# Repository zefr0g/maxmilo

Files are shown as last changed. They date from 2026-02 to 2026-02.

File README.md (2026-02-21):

# maxmilo - Contrôleur ESPHome pour Climatiseurs Mitsubishi

Ce projet vous permet de contrôler votre unité CVC Mitsubishi (avec un port CN105) en utilisant un ESP8266 (ESP-01) et ESPHome. Il remplace l'interface WiFi Mitsubishi originale **MAC-587IF-E** pour une fraction du prix, tout en offrant plus de fonctionnalités. Il est basé sur l'excellent travail de [echavet/MitsubishiCN105ESPHome](https://github.com/echavet/MitsubishiCN105ESPHome).

Il offre une interface moderne via Home Assistant ou un navigateur web, et dispose d'un portail captif pour une configuration WiFi facile.

[🇬🇧 Read the English version here](README_EN.md)

<p align="center">
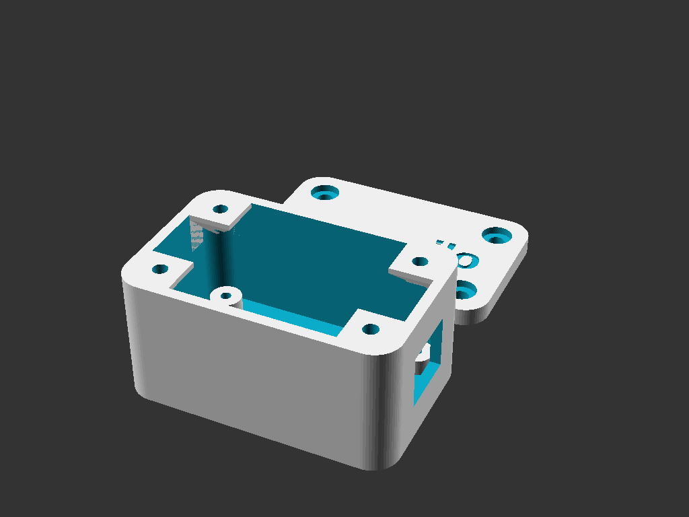
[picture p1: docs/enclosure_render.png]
Rendu 3D du boîtier
  
</p>

<p align="center">
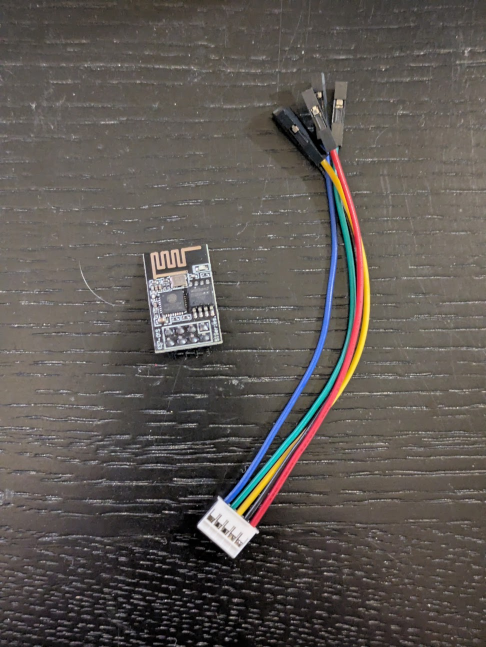
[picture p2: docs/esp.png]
ESP-01 et câble CN105
  
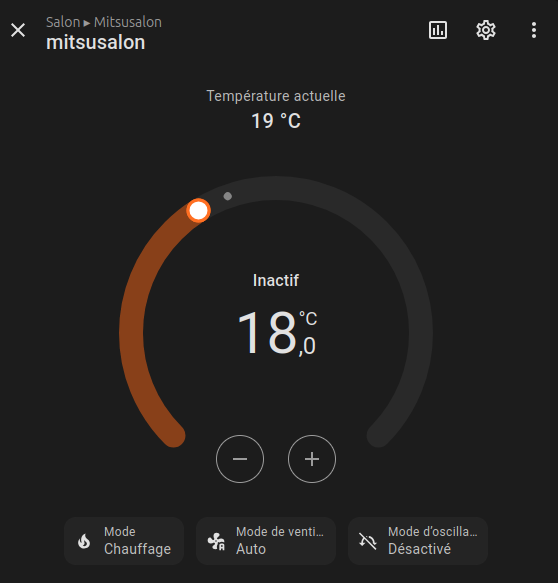
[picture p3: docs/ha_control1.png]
Interface Home Assistant 1
  
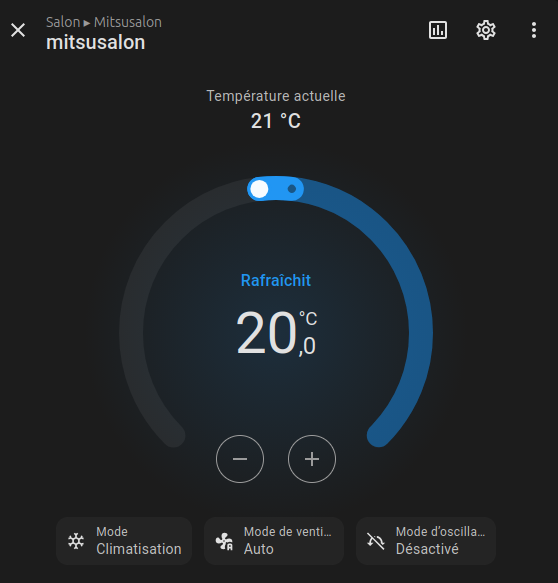
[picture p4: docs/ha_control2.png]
Interface Home Assistant 2
  
</p>

## 🚀 Fonctionnalités

- **Installation en un clic :** Via l'installateur web, sans ligne de commande.
- **Portail Captif WiFi :** Connectez-vous au point d'accès du module pour configurer votre réseau local.
- **Renommage dynamique :** Changez le nom de votre unité directement depuis l'interface web.
- **Diagnostics Avancés :** Suivi de la force du signal WiFi (RSSI) et de l'uptime.
- **Intégration Home Assistant :** Découverte automatique via l'API Native.

## 📖 Documentation
- **[Guide d'Installation Étape par Étape](docs/installation.md)**
- **[Plan de la future carte PCB](docs/pcb_plan.md)**
- **Matériel Open Source :** Boîtier imprimable en 3D avec fixations sécurisées.

## 🛠 Matériel Requis

Pour fabriquer ce contrôleur, vous aurez besoin de :

1.  **Module ESP8266 ESP-01**
2.  **Adaptateur Série WiFi ESP-01** (Assure la régulation 5V vers 3.3V et l'adaptation de niveau logique)
3.  **Connecteur JST PAP-05V-S** (Connecteur 5 broches pour le port CN105)
4.  **Boîtier maxmilo** (Fichier SCAD fourni dans `hardware/`)

### Schéma de câblage (CN105 vers ESP-01)

| Broche CN105 | Fonction | Adaptateur ESP-01 |
| :--- | :--- | :--- |
| 1 | 12V | Non Connecté |
| 2 | GND | GND |
| 3 | 5V | VCC (5V) |
| 4 | TX | RX (GPIO3) |
| 5 | RX | TX (GPIO1) |

> ⚠️ **Attention :** Assurez-vous que votre adaptateur gère bien la conversion de niveau 5V vers 3.3V pour protéger l'ESP-01.

## 💻 Installation

### Option A : Installateur Web (Recommandé)
Flashez votre ESP-01 directement depuis votre navigateur (Chrome/Edge) sans rien installer !
👉 **[Cliquez ici pour utiliser l'Installateur Web maxmilo](https://zefr0g.github.io/maxmilo/web_installer/)**

### Option B : Installation Manuelle (CLI)
Si vous préférez compiler vous-même :

#### 1. Installer ESPHome
```bash
pip install esphome
```

#### 2. Flasher le Firmware
```bash
esphome run example.yaml
```

## 💰 Acheter un Kit
Vous ne voulez pas sourcer les pièces vous-même ? [Ouvrez une Issue sur GitHub](https://github.com/zefr0g/maxmilo/issues) pour commander un kit prêt à l'emploi.

## 🤝 Contribution
Les contributions sont les bienvenues ! N'hésitez pas à ouvrir une issue ou une pull request.

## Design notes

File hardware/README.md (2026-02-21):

# Matériel maxmilo - Liste des Pièces & Assemblage

Ce dossier contient les informations sur les composants physiques et le processus d'assemblage.

[🇬🇧 English version available here](README_EN.md)

## 📦 Liste des Pièces (BOM)

| Qté | Article | Description | Prix Approx. |
| :--- | :--- | :--- | :--- |
| 1 | ESP8266 ESP-01 | Microcontrôleur (Wi-Fi) | ~$2.00 |
| 1 | Adaptateur Série ESP-01 | Régulateur 5V et adaptateur de niveau | ~$1.50 |
| 1 | JST PAP-05V-S | Connecteur 5 broches (pour CN105) | ~$0.50 |
| 1 | Boîtier imprimé 3D | Boîtier pour les modules | (Minimal) |
| 4 | Inserts filetés M3 | Inserts à chaud pour fixer le couvercle | ~$1.00 |

## 💰 Acheter le Kit

- **Kit DIY :** Tous les composants inclus. Vous assemblez et flashez.
- **Assemblé & Pré-flashé :** Prêt à l'emploi.

### Comment commander
Pour acheter, merci d'**[ouvrir une issue sur GitHub](https://github.com/zefr0g/maxmilo/issues)**.

## 🛠 Instructions d'Assemblage

1.  **Préparer le connecteur :** Sertissez le connecteur PAP-05V-S avec 4 fils (GND, 5V, TX, RX).
2.  **Câblage :**
    - CN105 Pin 2 (GND) -> Adaptateur GND
    - CN105 Pin 3 (5V) -> Adaptateur VCC
    - CN105 Pin 4 (TX) -> Adaptateur RX
    - CN105 Pin 5 (RX) -> Adaptateur TX
3.  **Insérer l'ESP-01 :** Branchez le module dans le socket de l'adaptateur.

## 📂 Fichiers du Boîtier
- `enclosure.scad` : Script OpenSCAD professionnel et rapide.
- `box.stl` : Le corps principal du boîtier.
- `lid.stl` : Le couvercle avec gravure "maxmilo".

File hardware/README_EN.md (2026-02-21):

# maxmilo Hardware - Bill of Materials & Assembly

This folder contains information about the physical components and the assembly process.

## 📦 Bill of Materials (BOM)

| Qty | Item | Description | Approx. Price |
| :--- | :--- | :--- | :--- |
| 1 | ESP8266 ESP-01 | Microcontroller (Wi-Fi) | ~$2.00 |
| 1 | ESP-01 Serial Adapter Module | Logic level shifter and 5V regulator | ~$1.50 |
| 1 | JST PAP-05V-S | 5-pin 2.0mm pitch connector (for CN105) | ~$0.50 |
| 5 | Female DuPont Wires | To connect adapter to CN105 (if not using a custom cable) | ~$0.50 |
| 1 | Custom 3D Printed Case | Enclosure for the modules | (Minimal) |
| 4 | M3 Threaded Inserts | Heat-set inserts for fixing the lid | ~$1.00 |

## 💰 Buy the Kit

Don't want to source the parts yourself? Buy a pre-tested kit directly from me!

- **DIY Kit:** All components (ESP-01, Adapter, Connector, 3D Printed Case) included. You assemble and flash.
- **Assembled & Pre-flashed:** Ready to plug-and-play. I will pre-flash it with your WiFi credentials if provided.

### How to Order
To purchase, please [open an issue](https://github.com/zefr0g/maxmilo/issues) or contact me at: **[Insert Your Email/PayPal/Link Here]**

## 🛠 Assembly Instructions

1.  **Prepare the Connector:** Crimp the PAP-05V-S connector with 5 wires (only 4 are strictly needed: GND, 5V, TX, RX).
2.  **Logic Level Shifting:** The Mitsubishi CN105 port uses 5V logic. **The ESP-01 uses 3.3V.** You **MUST** use a logic level shifter or an adapter that handles this. The adapter module mentioned in the BOM typically does this.
3.  **Wiring:**
    - CN105 Pin 2 (GND) -> Adapter GND
    - CN105 Pin 3 (5V) -> Adapter VCC
    - CN105 Pin 4 (TX) -> Adapter RX
    - CN105 Pin 5 (RX) -> Adapter TX
4.  **Insert ESP-01:** Plug the ESP-01 module into the adapter's socket.
5.  **Enclosure:** Secure the components inside the 3D printed case and route the cable out.

## 📂 Enclosure Files
- `enclosure.scad`: Professional, fast-rendering OpenSCAD script.
- `box.stl`: Main enclosure body.
- `lid.stl`: Lid with "maxmilo" branding.

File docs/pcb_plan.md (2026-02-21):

# Plan de Conception : Carte PCB Personnalisée maxmilo

L'objectif est de remplacer l'empilement actuel (ESP-01 + Adaptateur bleu) par une carte unique, compacte et professionnelle, fabricable à faible coût (ex: JLCPCB, PCBWay).

## 🎯 Objectifs
- **Taille :** Réduire l'encombrement de 50%.
- **Fiabilité :** Éliminer les fils DuPont et les faux contacts.
- **Coût :** Réduire le coût de revient unitaire en commandant des séries assemblées (PCBA).

## 🛠 Spécifications Techniques

### 1. Microcontrôleur : ESP-12F (ESP8266)
- Plus robuste que l'ESP-01.
- Antenne intégrée certifiée.
- Plus de pins disponibles pour de futures extensions (ex: capteur d'humidité).

### 2. Alimentation (Buck Converter ou LDO)
- Entrée : 5V (venant du port CN105).
- Sortie : 3.3V stable pour l'ESP.
- Protection contre les inversions de polarité et les pics de tension.

### 3. Adaptation de Niveau Logique (Level Shifting)
- Le CN105 communique en 5V, l'ESP en 3.3V.
- Utilisation de transistors (BSS138) ou d'un buffer (74LVC245) pour une communication série propre à 2400 bauds.

### 4. Connectique
- Empreinte pour connecteur **JST PH 2.0mm 5-pin** (plus compact et sécurisé que le DuPont).
- Port de programmation (Pads pour sondes ou port USB-C minimaliste pour le debug).

### 5. Composants SMD
- Résistances et condensateurs en boîtier **0603** ou **0805** (faciles à souder ou à faire assembler).
- Régulateur de tension type **AMS1117-3.3** ou **AP2112K**.

## 📅 Étapes du Projet
1.  **Schématique (KiCad) :** Dessiner le circuit en intégrant les composants de protection.
2.  **Routage (PCB) :** Optimiser le placement pour que la carte tienne dans un boîtier encore plus petit.
3.  **Prototypage :** Commander 5 exemplaires pour valider le fonctionnement.
4.  **Production :** Lancer une série de 50 à 100 unités avec assemblage des composants (SMD Assembly).

## 📦 Boîtier futur
Une fois la carte finale prête, le fichier `enclosure.scad` sera mis à jour pour un design "snap-fit" ultra-compact ne nécessitant potentiellement plus de vis.

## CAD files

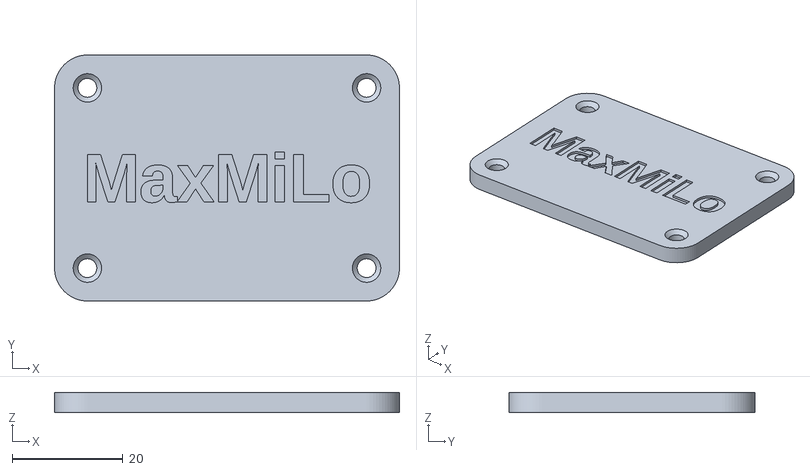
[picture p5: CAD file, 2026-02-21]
hardware/lid.stl
62.4 x 44.5 x 3.70

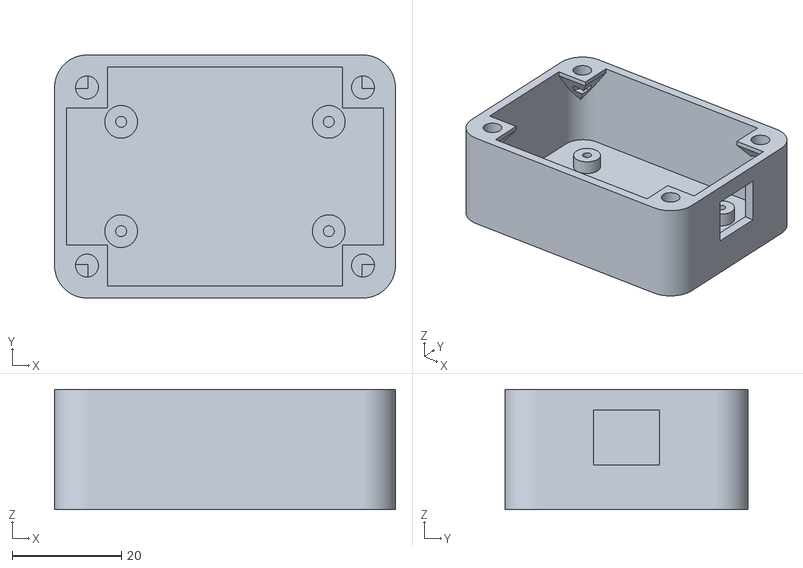
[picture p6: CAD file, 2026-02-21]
hardware/box.stl
62.4 x 44.5 x 22.0

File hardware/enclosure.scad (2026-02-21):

// maxmilo - Extra-Safe Professional Enclosure
// Optimized for ESP-01 Adapter (42mm x 24.1mm) with tall components

$fn = 64;

// PCB Dimensions
pcb_l = 42.0;
pcb_w = 24.1;
pcb_hole_dist_x = 38.0; 
pcb_hole_dist_y = 20.0;
pcb_h_offset = 3; 

// Enclosure Dimensions - Increased margin for safety
inner_l = pcb_l + 16; 
inner_w = pcb_w + 16;
height = 22; // Slimmer profile (down from 26mm)
wall = 2.2;  // Thicker walls for better insert retention
corner_r = 6;

// Screws & Inserts
m3_insert_d = 4.2; 
m3_insert_depth = 6.0;
m3_clearance_d = 3.4;
support_size = 7.5; // Small enough to stay outside the PCB area

module rounded_box(l, w, h, r) {
    hull() {
        translate([r, r, 0]) cylinder(r=r, h=h);
        translate([l-r, r, 0]) cylinder(r=r, h=h);
        translate([r, w-r, 0]) cylinder(r=r, h=h);
        translate([l-r, w-r, 0]) cylinder(r=r, h=h);
    }
}

module box() {
    difference() {
        union() {
            // Main Hollow Shell
            difference() {
                rounded_box(inner_l + 2*wall, inner_w + 2*wall, height, corner_r);
                translate([wall, wall, wall])
                    rounded_box(inner_l, inner_w, height + 1, corner_r - wall/2);
            }
            
            // Hanging Corner Supports (45 degree slope)
            // Positioned exactly in the corners to stay away from the PCB
            for (x = [wall, inner_l + wall - support_size])
                for (y = [wall, inner_w + wall - support_size])
                    translate([x, y, height - 10])
                    intersection() {
                        cube([support_size, support_size, 10]);
                        hull() {
                            translate([0,0,9]) cube([support_size, support_size, 1]);
                            // Anchors to walls
                            if (x == wall && y == wall) translate([0,0,0]) cube([1,1,1]);
                            if (x > wall && y == wall) translate([support_size-1,0,0]) cube([1,1,1]);
                            if (x == wall && y > wall) translate([0,support_size-1,0]) cube([1,1,1]);
                            if (x > wall && y > wall) translate([support_size-1,support_size-1,0]) cube([1,1,1]);
                        }
                    }
        }
        
        // Subtract Functional Cutouts
        // Cable Cutout
        translate([inner_l + wall - 1, (inner_w + 2*wall)/2 - 6, wall + 6])
            cube([wall + 2, 12, 10]);
            
        // Screw Holes for Inserts (Centered in supports)
        for (x = [wall + support_size/2, inner_l + wall - support_size/2])
            for (y = [wall + support_size/2, inner_w + wall - support_size/2])
                translate([x, y, height - m3_insert_depth + 0.1])
                    cylinder(d = m3_insert_d, h = m3_insert_depth + 1);
    }

    // PCB Mounting Posts (Centrally located)
    translate([wall + (inner_l-pcb_l)/2, wall + (inner_w-pcb_w)/2, wall]) {
        off_x = (pcb_l - pcb_hole_dist_x)/2;
        off_y = (pcb_w - pcb_hole_dist_y)/2;
        
        for (ax = [off_x, off_x + pcb_hole_dist_x])
            for (ay = [off_y, off_y + pcb_hole_dist_y])
                translate([ax, ay, 0])
                    difference() {
                        cylinder(d = 6, h = pcb_h_offset);
                        translate([0,0,1]) cylinder(d = 2.0, h = pcb_h_offset + 1);
                    }
    }
}

module lid() {
    difference() {
        rounded_box(inner_l + 2*wall, inner_w + 2*wall, wall + 1.5, corner_r);
        
        // Screw Holes aligned with the supports
        for (x = [wall + support_size/2, inner_l + wall - support_size/2])
            for (y = [wall + support_size/2, inner_w + wall - support_size/2]) {
                translate([x, y, -1]) cylinder(d = m3_clearance_d, h = wall + 4);
                // Chamfer for screw head
                translate([x, y, wall + 0.5]) cylinder(d1=m3_clearance_d, d2=6, h=1.5);
            }
            
        // Branding
        translate([(inner_l+2*wall)/2, (inner_w+2*wall)/2, wall + 1.0])
            linear_extrude(height = 1)
                text("MaxMiLo", size = 9, font = "Liberation Sans:style=Bold", halign = "center", valign = "center");
    }
}

// Multi-part export logic
part = "all"; // [all, box, lid]

if (part == "all") {
    box();
    translate([0, inner_w + 2*wall + 10, 0]) lid();
} else if (part == "box") {
    box();
} else if (part == "lid") {
    lid();
}

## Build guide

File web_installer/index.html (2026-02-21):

# maxmilo Installer

Bienvenue ! Cet outil vous permet d'installer le firmware maxmilo directement depuis votre navigateur.

Connectez votre ESP-01 (via USB) et cliquez sur "Connect".

Compatible avec Chrome, Edge et Opera.
Assurez-vous d'avoir les drivers CH340/CP2102 installés.

Retour au projet GitHub (https://github.com/zefr0g/maxmilo)

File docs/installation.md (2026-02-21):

# Guide d'Installation maxmilo

Félicitations pour votre achat du contrôleur **maxmilo** ! Ce guide vous aidera à installer et configurer votre unité en toute sécurité.

## ⚠️ Sécurité d'abord
*   **Coupez l'alimentation électrique** de votre climatiseur au niveau du disjoncteur avant toute intervention.
*   Ne forcez jamais sur les connecteurs.
*   Si vous n'êtes pas à l'aise, faites appel à un professionnel.

## 🛠 Étape 1 : Accéder au port CN105
1.  Ouvrez le capot avant de votre unité intérieure Mitsubishi.
2.  Localisez le boîtier de commande électrique (généralement à droite).
3.  Retirez les vis du couvercle du boîtier pour accéder à la carte mère.
4.  Cherchez un connecteur rouge à 5 broches marqué **CN105**.

## 🔌 Étape 2 : Branchement
1.  Branchez le connecteur blanc de votre câble maxmilo sur le port rouge **CN105**.
2.  Positionnez le boîtier maxmilo dans un espace libre (il est assez petit pour tenir dans le compartiment câblage).
3.  Refermez le couvercle et le capot de l'unité.

## ⚡ Étape 3 : Mise en route
1.  Rétablissez le courant.
2.  L'unité maxmilo va démarrer et créer un réseau WiFi nommé `Ma Climatisation Setup-xxxxxx`.
3.  Connectez-vous avec votre téléphone et suivez les instructions à l'écran pour connecter l'unité à votre WiFi domestique.

## 📱 Étape 4 : Utilisation
*   **Home Assistant :** L'unité sera automatiquement détectée. Cliquez sur "Configurer".
*   **Navigateur Web :** Accédez à `http://maxmilo-xxxxxx.local` (ou l'adresse IP fournie par votre box) pour contrôler l'unité directement.

---
En cas de problème, ouvrez une issue sur : [https://github.com/zefr0g/maxmilo](https://github.com/zefr0g/maxmilo)

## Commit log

2026-02-21 Add 3D printable enclosure script and pricing info
    [enclosure.scad]
2026-02-21 Enhance enclosure: rounded edges and 'maxmilo' text on lid
    [enclosure.scad]
2026-02-21 Passage en Français par défaut, ajout de l'anglais et mise à jour des liens d'achat
2026-02-21 Mise à jour boîtier : fixations PCB 42x24.1mm et fermeture par vis
    [enclosure.scad]
2026-02-21 Design boîtier : ajout piliers coniques et élargissement pour montage aisé
    [enclosure.scad]
2026-02-21 Design boîtier : supports de vis inversés pour libérer l'espace PCB au sol
    [enclosure.scad]
2026-02-21 Add enclosure render and Home Assistant captures to READMEs
2026-02-21 Design: optimized SCAD and exported box/lid STL files
    [box.stl, enclosure.scad, lid.stl]
2026-02-21 Design: added support for M3 threaded inserts in the enclosure
    [box.stl, enclosure.scad, lid.stl]
2026-02-21 Fix: correctly subtracted screw holes from corner supports in box design
    [box.stl, enclosure.scad, lid.stl]
2026-02-21 Fix: correctly restored corner supports and drilled insert holes
    [box.stl, enclosure.scad, lid.stl]
2026-02-21 Design: increased enclosure size to ensure PCB fits with tall components
    [box.stl, enclosure.scad, lid.stl]
2026-02-21 Design: reduced enclosure height to 22mm for a sleeker profile
    [box.stl, enclosure.scad, lid.stl]
2026-02-21 Design: updated lid lettering to 'MaxMiLo'
    [enclosure.scad, lid.stl]
